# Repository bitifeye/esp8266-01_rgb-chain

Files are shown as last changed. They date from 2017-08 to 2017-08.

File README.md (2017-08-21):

# An RGB-Chain controlled by the ESP-01
This is an project to control a RGB-chain with the ESP-01 by WiFi.
The Esp-01 will programmed by the Arduini IDE and fit in a selfmade circuit board which will replace the old one of the RGB-chain.

## Components
To run the project you need some components. 
You find a list of them [here](https://github.com/bitifeye/esp8266-01_rgb-chain/blob/master/component_list.txt).

## Folder structure
Exery folder has its own readme for more details.
- [components](https://github.com/bitifeye/esp8266-01_rgb-chain/blob/master/component_list.txt)
  Here will you find a list of all components you need.

- [pcb](https://github.com/bitifeye/esp8266-01_rgb-chain/tree/master/pcb)
  Here will you find informations about the circuit board.

- [src](https://github.com/bitifeye/esp8266-01_rgb-chain/tree/master/src)
  In this folder is the sourcecode.
  You will also find some information how to use it.
  
## Using
Create the cuircit board by following the [instructions](https://github.com/bitifeye/esp8266-01_rgb-chain/blob/master/pcb/README.md). Programm the ESP-01 with the main.ino and stick him in the cuircit board.<br>
After that the ESP-01 will create an AP by default with name: "ESP-01". There is no password. If you are connected to the ESP-01 you can call him by "esp8266.local" form your PC. For this you have to install the [Bonjour](https://support.apple.com/bonjour), if you use an Linux-System use the [Avahi](http://avahi.org/). Calling the hostname don't work with an Android-System yet.
After calling the ESP-01 you can get the IP-Address by clicking the appropriate button. With this IP-Address you can use the system with any devices.<br>
If you set a new WiFi-connection, e.g. your own WiFi-network, the ESP-01 try to connect as a station, if that fail it create an AP agin. For that use the SSID of your network (the WiFi-name) and the matching password.<br>
For using the system by a smartphone, you have to look for the IP-Address. Either look in your router or call by your PC "esp8266.local" in your browser and click the "Get the IP-Address"-button. Now you can see the IP-Address which you can use to connect your smartphone or tablet.<br>
Make sure that the ESP-01 and the using device are both in the same network. Otherwise it will not work yet.
  
## Possible extensions of the project
- The circuit board has the opportunity to receive th IR-signal from the old remote controler.
  But the code for that aren't implemented yet.

## License
The whole project is under the GPLv3.<br>
For more ditails have a look in the [License](https://github.com/bitifeye/esp8266-01_rgb-chain/blob/master/LICENSE)

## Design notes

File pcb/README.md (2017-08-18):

## Here you get a description what you need to do to get the circuit board.

### Steps:
1.	Install "KiCad". It can be downladed here: http://kicad-pcb.org/
2.	Open KiCad and open the kicad-project. You find it in the folder "PCB" and it ends on ".pro".
3.	If you want you can change now somthing in the schematic or in the laylout.
4.	If you done, search for an provider of PCB-production. A good one is PCB-Pool (https://www.pcb-pool.com/)

	But you can choose your own. You can find a list here: https://www.mikrocontroller.net/articles/Platinenhersteller
	
	Check what kind of files (gerber-files or the pcb-files) your provider need. KiCad can also generate the gerber-files.
	If you make your order make sure that the circuit  board only has a depth of 1,0mm. Otherwise it will not fit in the control box.
5.	While your PCB is in processing you can order the components for the board. For that have a look in the [component_list.txt](https://github.com/bitifeye/esp8266-01_rgb-chain/blob/master/component_list.txt).
6.	If you have your board and the components you can solder everything on its position.
	For the connection to the RGB-LED-Chain you can use the old cabels. Unsolder the cabels from the old circuit 
7.	If you connect the cabels to the RGB-LED-Chain make sure you connect the right one to the appropriate hole.
	Do not trust the color of the cabel-isolation.

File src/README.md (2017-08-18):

# Here you get a description what you need to do to program and run the ESP-01.
First of all download the project and especially the **src** folder.

## Downloads and instalation:
1.	Install the [Arduino IDE](https://www.arduino.cc/en/Main/Software)
2.	Install the ESP8266 Platform to your "Arduino IDE". 

	Have a look on this pictures 
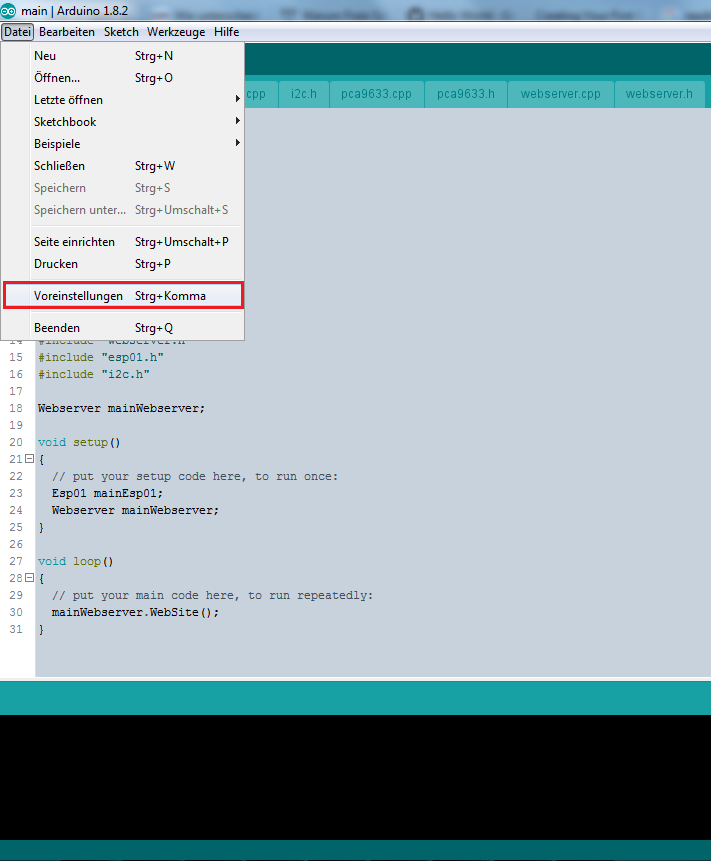
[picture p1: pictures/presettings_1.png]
		 
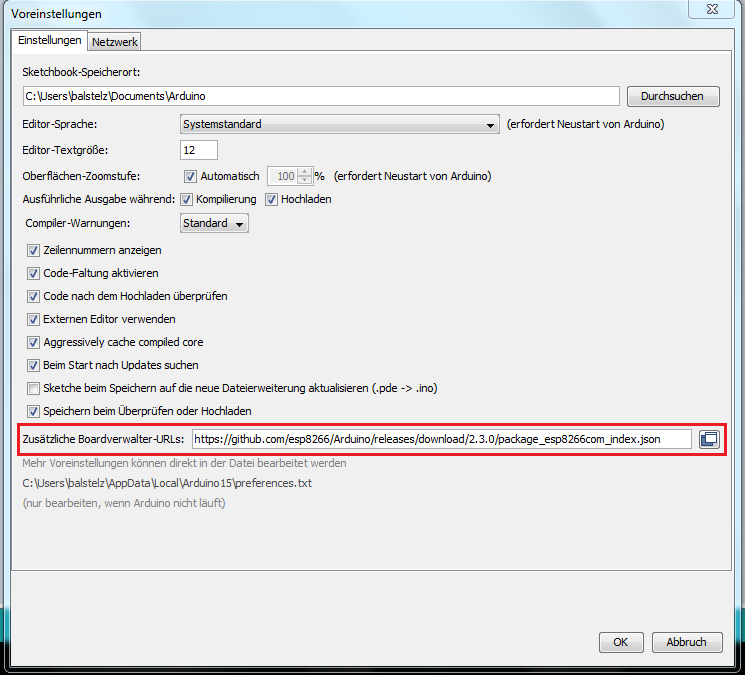
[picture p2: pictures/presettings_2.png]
		
	
	Put the following link in the "Additional Board Manager URLs field"
	
		- http://arduino.esp8266.com/stable/package_esp8266com_index.json
	If this link don't work use
	
		- http://arduino.esp8266.com/staging/package_esp8266com_index.json
	
	Restart your Arduino IDE.
	
	Install the *esp8266* plattform in the board manager as shown on the following pictures
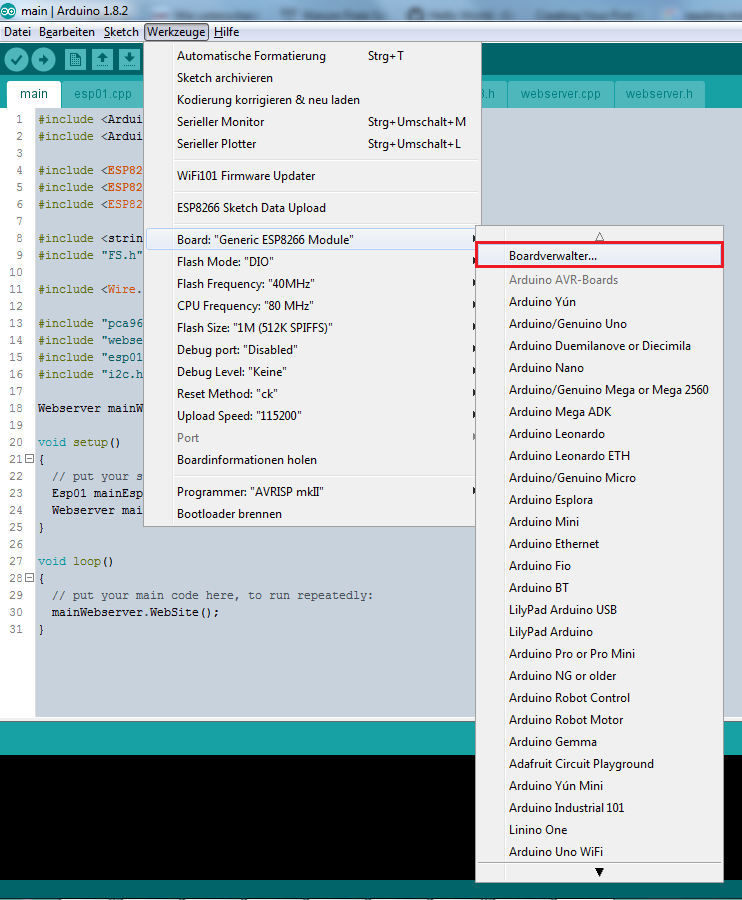
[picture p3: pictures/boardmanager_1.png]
		 
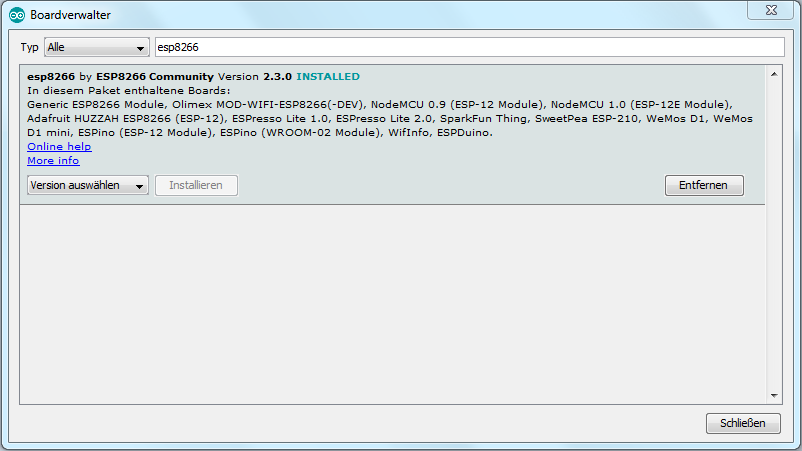
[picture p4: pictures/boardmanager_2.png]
		
		
	or you can follow this [link](http://esp8266.github.io/Arduino/versions/2.0.0/doc/installing.html#boards-manager)
3.	Install the [SPIFFS](http://www.instructables.com/id/Using-ESP8266-SPIFFS/) by following this manual until Step 3
4.	Install the "ArduinoJson"-library as shown on the pictures
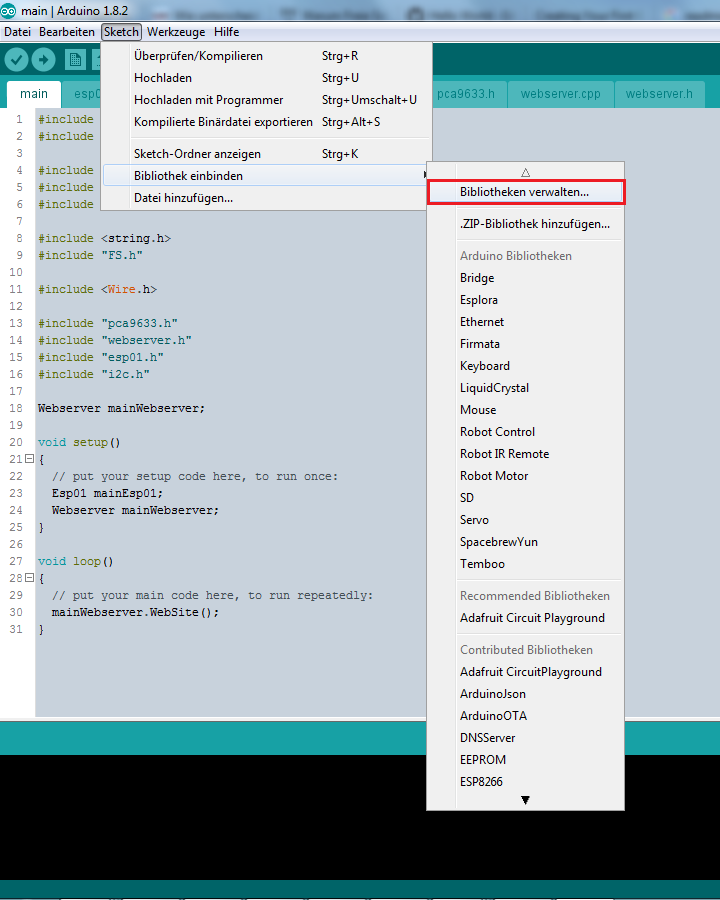
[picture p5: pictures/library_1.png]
	 
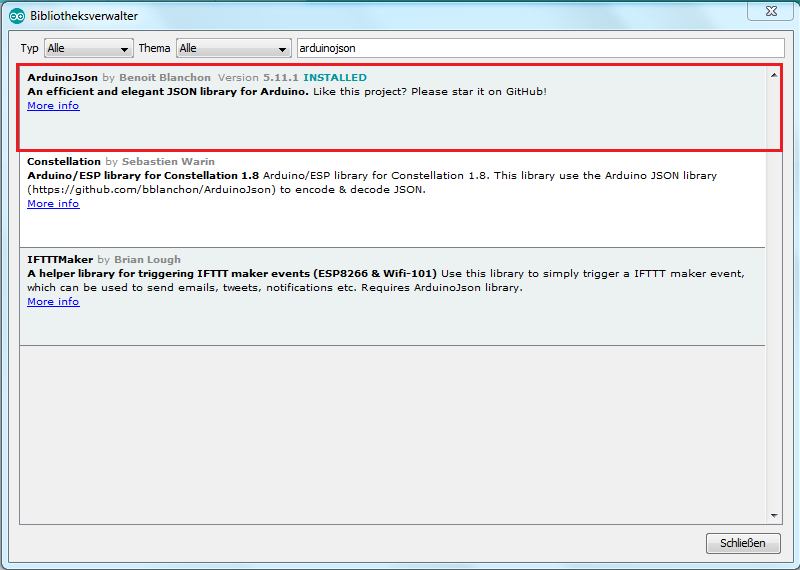
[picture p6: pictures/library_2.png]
	
5.	Install the [TTL-232R-Cabel-driver](https://cdn.sparkfun.com/assets/learn_tutorials/7/4/CDM_v2.12.00_WHQL_Certified.exe)	You can find a quick install tutorial [here](https://learn.sparkfun.com/tutorials/how-to-install-ftdi-drivers/all).
	
	If you use the ESP-01 programmer you don't have to do this step.

## Program the ESP-01:
1.	Open the "src/main" folder
2.	Open the main.ino in the folder with the Arduino IDE
3.	Connect the TTL-232R-Cabel to your PC
4. 	Set the right board-options as shown on the picture and select the right "COM"-Port
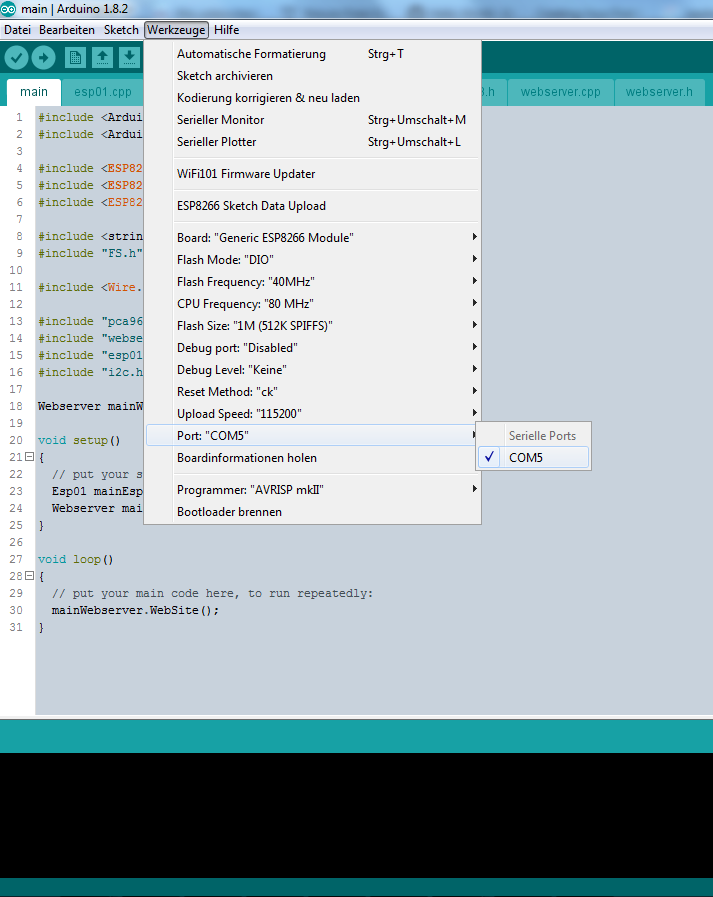
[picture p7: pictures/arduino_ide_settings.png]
	
5.	Connect your ESP-01 as shown on the [schematic](https://github.com/bitifeye/esp8266-01_rgb-chain/blob/master/pictures/programming_connections.png). Make sure that the ESP-01 only connect to an 3,3V DC-power-supply.
	For the right connection of the RX and TX have a look for the pinout at the [TTL-232R-Cabel datasheet](http://www.ftdichip.com/Support/Documents/DataSheets/Cables/DS_TTL-232R_CABLES.pdf).
	
	If you want you can also use an [ESP-01 programmer board](http://www.ebay.de/itm/like/262988751030?chn=ps&dispItem=1). Here you can get a good [interduction](https://www.xgadget.de/anleitung/esp-01-esp8266-mit-adapter-programmieren-so-gehts/)
6.	Reset your ESP-01 by pull the "RST"-Pin to "GND" and releas him again
7.	Upload the data-folder. Click Tools->ESP8266 Sketch Data Upload.
	Make sure that the "Serial Monitor" is closed while this process.
8.	Reset your ESP-01 again by repeating point 6.
9.	Upload the scetch by pressing "STRG+U" or click the upload-button in the left upper corner.
	If you want to see the fist debugging messages you can open the "Serial Monitor" and set him to the baud rate 9600. Do this befor you upload the scetch.
10.	If everything worked fine you can release the connections and put him in to the circuit board.
11.	Put the circuit board with the ESP-01 in the control box and close it. Connect the power supply and the RGB-LED-Chain.
	Connect your device to the ESP-01 and have fun.

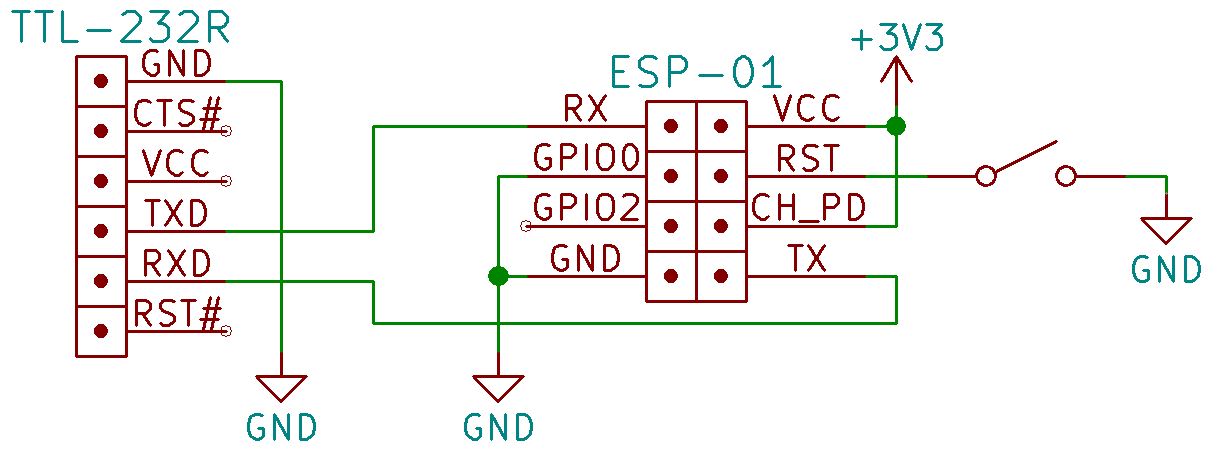
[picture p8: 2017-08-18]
pictures/programming_connections.png

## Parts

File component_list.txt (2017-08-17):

This is a list with all the components you need for the whole Projekt.
Here are also a possible link listed where you can buy these components. You don't have to use these providers.
You also need soldering station and solder.

Components for the PCB:
	- Resistor:
		- 1x 0ohm (1206) https://www.conrad.biz/de/dickschicht-widerstand-0-smd-1206-025-w-5-royalohm-1206s4j0000t5e-1-st-1460195.html
		- 3x 100ohm (1206) https://www.conrad.biz/de/dickschicht-widerstand-100-smd-1206-025-w-5-200-ppmc-royalohm-1206s4j0101t5e-1-st-1460223.html
	
	- Capacitor:
		- 2x 100nF (0805) https://www.conrad.biz/de/keramik-kondensator-0805-100000-pf-25-v-10-l-x-b-x-h-08-x-2-x-125-mm-wuerth-elektronik-wcap-csgp-885012207072-1-st-1279037.html
		- 1x 10uF (0805) https://www.conrad.biz/de/keramik-kondensator-1206-10-f-25-v-10-l-x-b-x-h-16-x-32-x-16-mm-wuerth-elektronik-wcap-csgp-885012208069-1-st-1278979.html
		
	- MOSFET:
		- 3x SI2312BDS https://www.conrad.biz/de/mosfet-vishay-si2312bds-t1-ge3-1-n-kanal-750-mw-sot-23-3-597303.html
		
	- PMIC-LED-Treiber:
		- 1x PCA9633DP1 https://www.conrad.biz/de/pmic-led-treiber-nxp-semiconductors-pca9633dp1118-stromschalter-tssop-8-oberflaechenmontage-1116591.html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
		
	- Voltage regulator:
		- 1x LD1117AS33TR https://www.conrad.de/de/spannungsregler-linear-stmicroelectronics-ld1117as33tr-sot-223-positiv-fest-1-a-1184681.html
	
	- Connectors:
		- 1x NEB 21 R https://www.conrad.de/de/niedervolt-steckverbinder-buchse-einbau-horizontal-6-mm-195-mm-lumberg-neb-21-r-1-st-738882.html
		- 1x Receptacle(2x4) https://www.conrad.biz/de/buchsenleiste-standard-anzahl-reihen-2-polzahl-je-reihe-4-econ-connect-bc8g-1-st-1311353.html
		- 1x Pin Header (2x3) https://www.conrad.biz/de/stiftleiste-standard-anzahl-reihen-2-polzahl-je-reihe-3-connfly-1390118-1-st-1390118.html
		
Other Components:
	- 1x ESP-01 https://www.ebay.de/i/191768591033?chn=ps&dispItem=1
	- 1x TTL-232R http://www.mouser.de/ProductDetail/FTDI/TTL-232R-3V3/?qs=Xb8IjHhkxj627GFcejHp0Q==
	- 1x RGB-LED-Chain(12VDC) https://www.amazon.de/COSANSYS-Wasserdicht-Lichtleisten-Farbwechsel-Fernbedienung/dp/B06XWCSP53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

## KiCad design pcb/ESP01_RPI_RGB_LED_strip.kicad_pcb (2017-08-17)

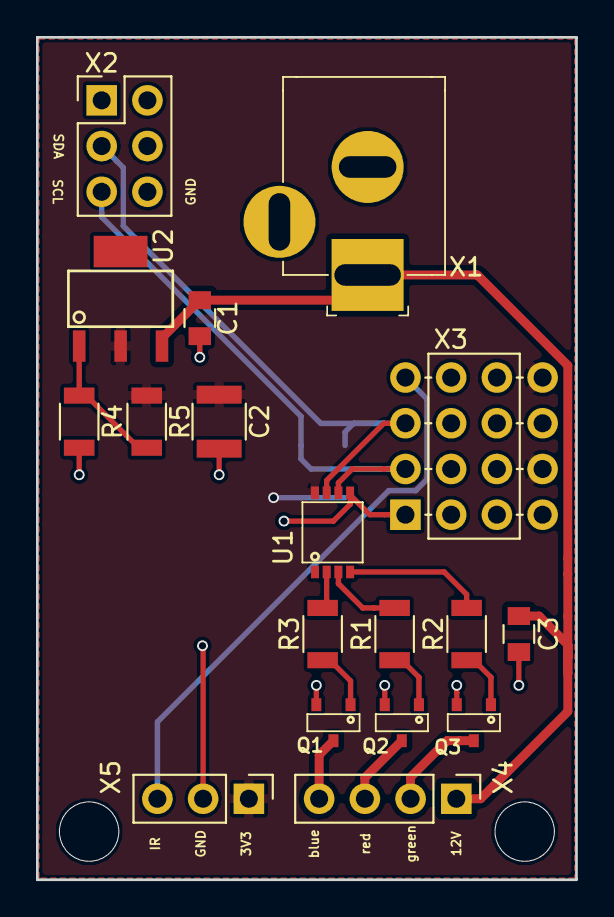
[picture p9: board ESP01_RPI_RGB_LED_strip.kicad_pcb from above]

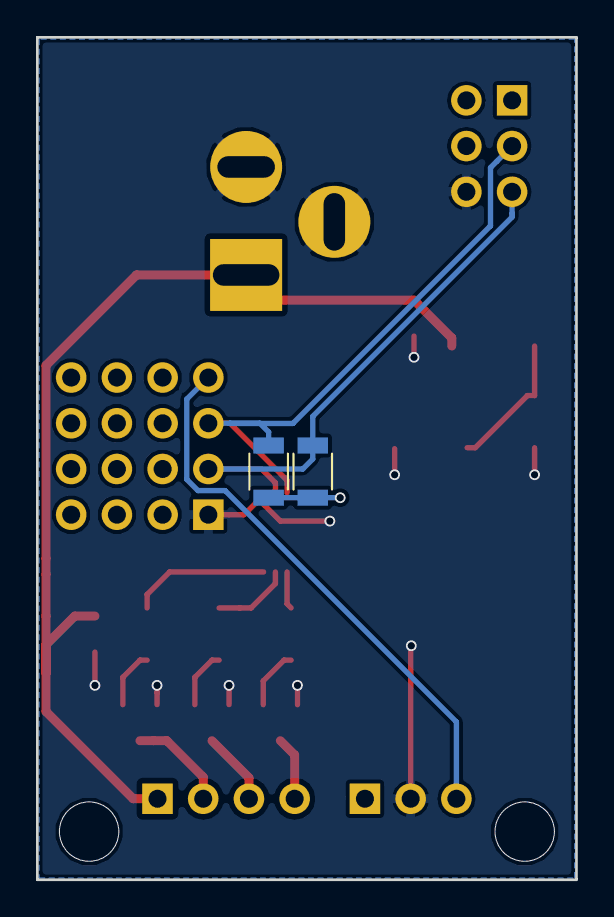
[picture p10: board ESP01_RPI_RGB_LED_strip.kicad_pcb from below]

Board: 2 copper layers, 29.9 x 46.8 mm, 20 parts (2 on the bottom side), 16 nets.

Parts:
C1, C3: 100n; C_0805
C2: 10u; C_1210
Q1, Q2, Q3: Si2312BDS
R1, R2, R3: 100; R_1206
R4: 0; R_1206
R5, R6, R7: No-R; R_1206
U1: PCA9633DP1
U2: LD1117A; LD1117AS33TR
X1: 1x2-Pin_Hedaer; DC-10A
X2: 2x3-Pin_Hedaer; Pin_Header_Straight_2x03_Pitch2.54mm
X3: 2x4-Pin_Hedaer; Pin_Header_Straight_For_ESP-01_2x04_Pitch2.54mm
X4: 1x4-Pin_Hedaer; Pin_Header_Straight_1x04_Pitch2.54mm
X5: 1x3-Pin_Hedaer; Pin_Header_Straight_1x03_Pitch2.54mm

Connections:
+3V3: C2.1, R5.1, R6.1, R7.1, U1.8, U2.2, X3.4, X3.8, X5.1
+12V0: C1.1, C3.1, U2.3, X1.1, X4.1
GND: C1.2, C2.2, C3.2, Q1.2, Q2.2, Q3.2, R4.2, U1.5, X1.2, X1.3, X2.6, X3.1, X5.2
IR: X3.7, X5.3
unnamed: Q1.1, R3.1
unnamed: Q2.1, R1.1
unnamed: Q3.1, R2.1
unnamed: R1.2, U1.3
unnamed: R2.2, U1.4
unnamed: R3.2, U1.2
unnamed: R4.1, R5.2, U2.1
SCL: R6.2, U1.6, X2.5, X3.3
SDA: R7.2, U1.7, X2.3, X3.5
blue: Q1.3, X4.4
green: Q3.3, X4.2
red: Q2.3, X4.3

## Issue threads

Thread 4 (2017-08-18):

The Wire.requestFrom() should not be encapsulated by Wire.beginTransmission() and Wire.endTransmission().

Koepel, 2017-08-18:
The Wire.beginTransmission() and Wire.endTransmission() are only used when writing data.
The Wire.requestFrom() does a start, puts address on the I2C bus, reads data, and issues a stop. Nothing else is needed.

You can remove the Wire.beginTransmission() and Wire.endTransmission() around the Wire.requestFrom().

Since you are reading only one byte, you can just read the byte with Wire.read(). It will be -1 if there was a problem on the I2C bus.
To detect a problem you could use Wire.available() once to check if one byte was received.

bitifeye, 2017-08-21:
tanks for that information
we will check and improve that

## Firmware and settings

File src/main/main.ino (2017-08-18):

#include <Arduino.h>
#include <ArduinoJson.h>

#include <ESP8266WebServer.h>
#include <ESP8266mDNS.h>
#include <ESP8266WiFi.h>

#include <string.h>
#include "FS.h"

#include <Wire.h>

#include "pca9633.h"
#include "webserver.h"
#include "esp01.h"
#include "i2c.h"

Webserver mainWebserver;

void setup() 
{
	// put your setup code here, to run once:
	Esp01 mainEsp01;
	Webserver mainWebserver;
}

void loop() 
{
	// put your main code here, to run repeatedly:
	mainWebserver.WebSite();
}

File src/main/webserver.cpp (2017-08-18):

#include "webserver.h"

WiFiServer wifiServer(80);

Webserver::Webserver()
:
	webserverPca9633()
{
	StartServer();
	Serial.println("webserver constructor was called");
}

Webserver::~Webserver()
{
}

void Webserver::StartServer()
{
	wifiServer.begin();
	Serial.println("Server is running");
	MDNS.addService("http", "tcp", 80);
	if(WiFi.localIP() == ZeroIp)
	{
		Serial.println("\nconnect to your Esp as an AP");
		Serial.print("Connect to: http://");
		Serial.print(WiFi.softAPIP());
		Serial.println("/");
	}
	else
	{
		Serial.println("\nconnect to your own WiFi network");
		Serial.print("Connect to: http://");
		Serial.print(WiFi.localIP());
		Serial.println("/");
	}
}

void Webserver::OpenHtmlFile()
{
	if(SPIFFS.exists(htmlWebsite))
	{
		File f = SPIFFS.open(htmlWebsite, "r");
		if(!f)
		{
			Serial.println("can not read the file");
			Serial.println("");
		}
		else
		{
			String s;
			while(f.available())
			{
				s += f.readStringUntil('\n');
				
			}
			client.println(s);
		}
		f.close();
	}
}

void Webserver::WebSite()
{
	int clientTimeOutCounter = 0;
	OpenHtmlFile();
	client = wifiServer.available();
	if(!client)
		return;
	
	Serial.println("\nnew client");
	while(!client.available())
	{
		delay(1);
		clientTimeOutCounter++;

		if(clientTimeOutCounter >= 250)
		{
			Serial.println("Connection timeout");
			return;
		}
	}
	
	request = client.readStringUntil('\r');
	client.flush();
	
	if(request == "")
	{
		client.stop();
		return;
	}
	
	GetPathAndParameterString();
	
	if((path == DefaultWebsite) || (path == "/"))
		htmlWebsite = DefaultWebsite;
	else if(path == ConfigWebsite)
		htmlWebsite = ConfigWebsite;
	else if(path == GetIpAddressWebsite)
		client.print(PrintIpAddressToClient());
	
	while(parameterString.length() > 0)
	{
		ReadValuesFromParameterString();
		
		if(parameterString.length() >= 0)
		{
			if(color.startsWith("r"))
			{
				if(colorValue.toInt() > 255 || colorValue.toInt() < 0)
				{
					htmlWebsite = ColorOutOfRangeWebsite;
					Serial.println("red value is out of range");
					return;
				}
				pwmRedValue = (uint8_t)colorValue.toInt();
				webserverPca9633.WriteToPwm2(pwmRedValue);
				htmlWebsite = DefaultWebsite;
			}
			else if(color.startsWith("g"))
			{
				if(colorValue.toInt() > 255 || colorValue.toInt() < 0)
				{
					htmlWebsite = ColorOutOfRangeWebsite;
					Serial.println("green value is out of range");
					return;
				}
				pwmGreenValue = (uint8_t)colorValue.toInt();
				webserverPca9633.WriteToPwm3(pwmGreenValue);
				htmlWebsite = DefaultWebsite;
			}
			else if(color.startsWith("b"))
			{
				if(colorValue.toInt() > 255 || colorValue.toInt() < 0)
				{
					htmlWebsite = ColorOutOfRangeWebsite;
					Serial.println("blue value is out of range");
					return;
				}
				pwmBlueValue = (uint8_t)colorValue.toInt();
				webserverPca9633.WriteToPwm1(pwmBlueValue);
				htmlWebsite = DefaultWebsite;
			}
			
			if(color.startsWith("ssid"))
			{
				newSsid = ConvertUrlToString(colorValue);
				newSsidWasSet = true;
			}				
			else if(color.startsWith("password"))
				newPassword = ConvertUrlToString(colorValue);
		}
	}
	
	if(newSsidWasSet)
	{
		newSsidWasSet = false;
		SaveConfig();
		htmlWebsite = DefaultWebsite;
		OpenHtmlFile();
		if(!client.available())
			client.stop();
		delay(1000);
		ESP.restart();
	}
}

void Webserver::GetPathAndParameterString()
{
	startIndex = request.indexOf(GetStart);
	
	if(startIndex < 0)
	{
		Serial.println("no parameters are set");
		return;
	}
	
	startIndex +=+ GetStart.length();
	endSpaceIndex = request.indexOf(" ", startIndex);
	endQuestionmarkIndex = request.indexOf("?", startIndex);
	
	if(endSpaceIndex > 0)
	{
		if(endQuestionmarkIndex > 0)
		{
			path = request.substring(startIndex, endQuestionmarkIndex);
			parameterString = request.substring(endQuestionmarkIndex + 1, endSpaceIndex);
		}
		else
		{
			path = request.substring(startIndex, endSpaceIndex);
		}
	}
}

void Webserver::ReadValuesFromParameterString()
{
	int equalSignIndex = parameterString.indexOf("=");
	int ampersandIndex = parameterString.indexOf("&");
	
	if(equalSignIndex > 0)
	{
		color = parameterString.substring(0, equalSignIndex);
		if(ampersandIndex >= equalSignIndex)
		{
			colorValue = parameterString.substring(equalSignIndex + 1, ampersandIndex);
			parameterString = parameterString.substring(ampersandIndex + 1, parameterString.length());
		}
		else
		{
			colorValue = parameterString.substring(equalSignIndex + 1, parameterString.length());
			parameterString = "";
		}
	}
	else
	{
		color = "";
		colorValue = "";
	}
}

String Webserver::ConvertUrlToString(String url)
{
	String convertedString;
	int i;
	for(i = 0; i < url.length(); i++)
	{
		if(url[i] == '%')
		{
			String hex = url.substring(i + 1, i + 3);
			int number = HexCharToInt(hex[0]) * 16 + HexCharToInt(hex[1]);
			convertedString += (char)number;
			i += 2;
		}
		else if(url[i] == '+')
			convertedString += ' ';
		else
			convertedString += url[i];
	}
	return convertedString;
}

int Webserver::HexCharToInt(char c)
{
  const char *hex = "0123456789ABCDEF";
  for (int i = 0; i < 16; i++)
  {
	if (hex[i] == c)
	  return i;
  }
  return -1;
}

bool Webserver::SaveConfig() 
{
	Serial.println("Saving...");
	
	StaticJsonBuffer<400> jsonBuffer;
	JsonObject& json = jsonBuffer.createObject();
	json["ssid"] = newSsid;
	json["password"] = newPassword;
	
	File configFile = SPIFFS.open("/config.json", "w");
	if (!configFile)
	{
		Serial.println("Failed to open config file for writing");
		return false;
	}
	
	json.printTo(configFile);
	delay(1000);
	configFile.close();
	return true;
}

String Webserver::PrintIpAddressToClient()
{
	String s;
	s += "<html>";
	s += "<head> <meta charset=\"utf-8\">";
	s += "<title>get ip-address</title>";
	s += "</head>";
	s += "<body>";
	s += "<meta name=\"viewport\"content=\"width=device-width, initial-scale=1.0\" />";
	s += "<center>";
	s += "<br>";
	s += "connect your smartphone or tablet to: http://";
	if(WiFi.localIP() == ZeroIp)
		s += WiFi.softAPIP().toString();
	else
		s += WiFi.localIP().toString();
	s += "</center>";
	s += "</body>";
	s += "</html>";
	
	return s;
}

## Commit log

2017-08-17 added pcb
    added the necessary files for the pcb
    [ESP01_RPI_RGB_LED_strip.kicad_pcb, ESP01_RPI_RGB_LED_strip.sch]
2017-08-17 added the readme for the pcb
    here are the necessary steps to take if someone want to use the pcb
2017-08-18 added picture and links
    added picture and links for the the board manager setup
